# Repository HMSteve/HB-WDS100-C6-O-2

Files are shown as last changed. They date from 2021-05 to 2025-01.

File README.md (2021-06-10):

# HB-WDS100-C6-O-2

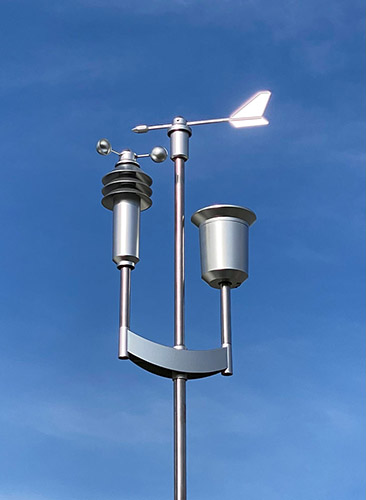
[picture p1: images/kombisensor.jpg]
HB-WDS100-C6-O-2


Ein "Reparaturset" fuer den Wetter-Kombisensor HM-WDS100-C6-O-2 auf Basis der AskSinPP-Bibliothek. Da Ausfaelle des originalen Wetter-Kombisensors wegen Korrosion der Hauptplatine offenbar nach einigen Jahren haeufiger vorkommen, die eigentliche Mechanik des Geraetes jedoch langlebig erscheint, wurde eine Ersatz-Elektronik sowie AskSinPP-basierte Firmware entwickelt, die es erlaubt, den Sensor ohne Modifikationen oder Addon-Installationen auf der CCU wieder zum Leben zu erwecken. Dazu sind sowohl die Hauptplatine als auch die Windrichtungsmesserplatine gegen die neu konzipierten Platinen auszutauschen und der Sensor neu anzulernen.

## Hardware

### Demontage des Kombisensors

Die Demontage des die Hauptplatine (und Batteriefach sowie Anemometer) tragenden Geraeteteils muss vorsichtig in folgenden Schritten erfolgen, um Schaeden an den Plastikteilen zu vermeiden:
1. Gehaeusehuelse ueber dem Batteriefach oeffnen und Batterien entfernen, Westernstecker loesen.
2. Beide Schrauben, die den Rotor mit den drei Schalen auf der Welle halten, leicht loesen und Rotor abziehen.
3. Zwei unter der Rotorkappe sichtbarwerdende vierkantige Arretierungsstifte aus Platik vorsichtig nach oben herausziehen (etwas mit dem Schraubenzieher hebeln, dann mit der Zange greifen und senkrecht herausziehen)
4. Die drei Ringe zum Sonnen- und Wetterschutz (Stevenson-Screen) mit dem oberen beginnend leicht im Urzeigersinn drehen, dass sich der jeweilige Bajonettverschluss loest, und Ring senkrecht nach oben abziehen.
5. Zwei kleine Schrauben ganz oben am Lager der Welle sowie danach fuenf lange Gehaeuseschrauben entfernen.
6. Zwei Schrauben, die den Aufbau auf dem Edelstahlrohr fixieren, loesen und Aufbau senkrecht nach oben aus dem Rohr Heraus ziehen
7. Die beiden Gehaeusehalbschalen lassen sich nun trennen und die defekte Platine ausbauen. Die Kabel koennen in der anderen Gehaeusehalbschale verbleiben.

Die Demontage der Windrichtungsmesserplatine ist unproblematisch.

### Ersatzplatinen

Als Ersatz sind zwei neue Platinen herzustellen: [Schalt- und Bestueckungsplaene sowie Gerberfiles](https://github.com/HMSteve/HB-WDS100-C6-O-2/tree/main/PCB).

Die Platinen sind bzgl. Bauteilbauformen, Padgroessen und Abstaenden grundsaetzlich fuer Handloetung vorgesehen, Details siehe unten.

Fuer die etwas spezielleren Bauteile finden sich Bezugsquellen hier: [Bezugsquellen](https://github.com/HMSteve/HB-WDS100-C6-O-2/tree/main/PCB/SourcingSpecialParts.xlsx)

### Hauptplatine

Die Platine basiert auf einem ATMega1284p. Die Temperatur-/Luftfeuchtemessung erfolgt mit einem SHT31, die Helligkeitsmessung mit einem [VEML6030](https://github.com/HMSteve/HB-WDS100-C6-O-2/blob/main/datasheets/VEML6030.pdf). Die Windgeschwindigkeit wird wie im Original per Reedkontakt gezaehlt, zur Reduzierung des Stromverbrauchs wird zum Zaehlen ein [PCF8593](https://github.com/HMSteve/HB-WDS100-C6-O-2/blob/main/datasheets/PCF8593.pdf) eingesetzt.

Ein paar Fotos vom Aufbau:

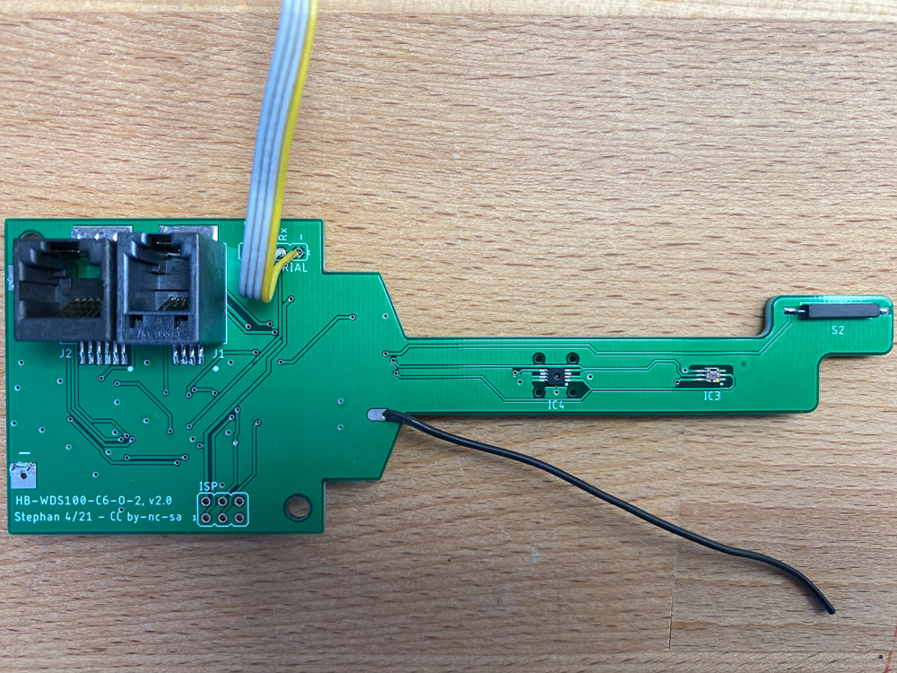
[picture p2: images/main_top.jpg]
PCB Top


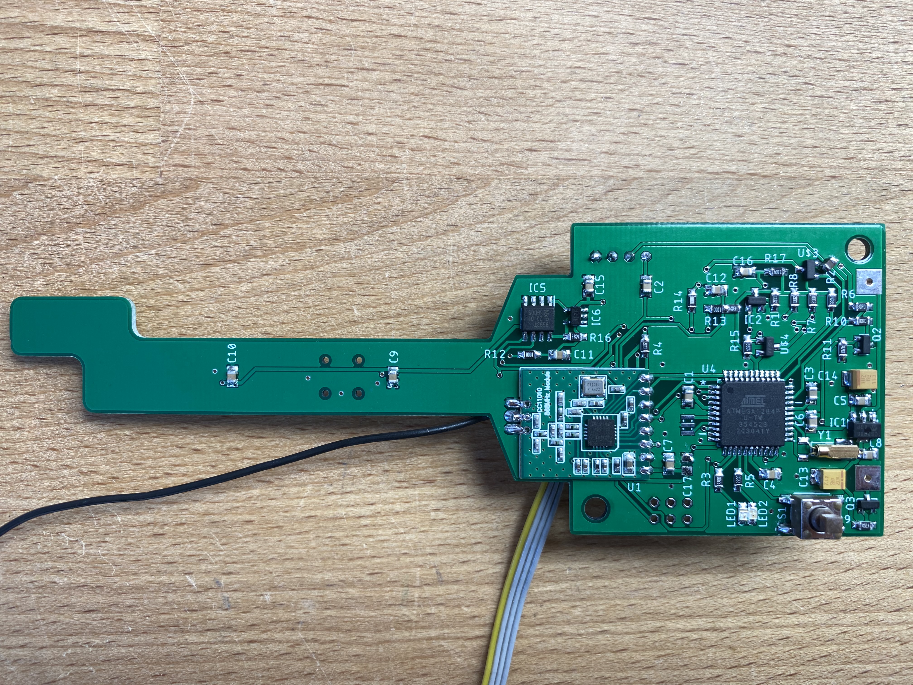
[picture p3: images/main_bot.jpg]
PCB Bottom


Bei Bestueckung der als Layout und Gerberfiles vorliegenden Platine v2.0 sind zwei Fehler zu korrigieren. Dazu ist jeweils etwas Loetstoplack zu entfernen, um die geaenderten Bauteilpostionen bestuecken zu koennen.

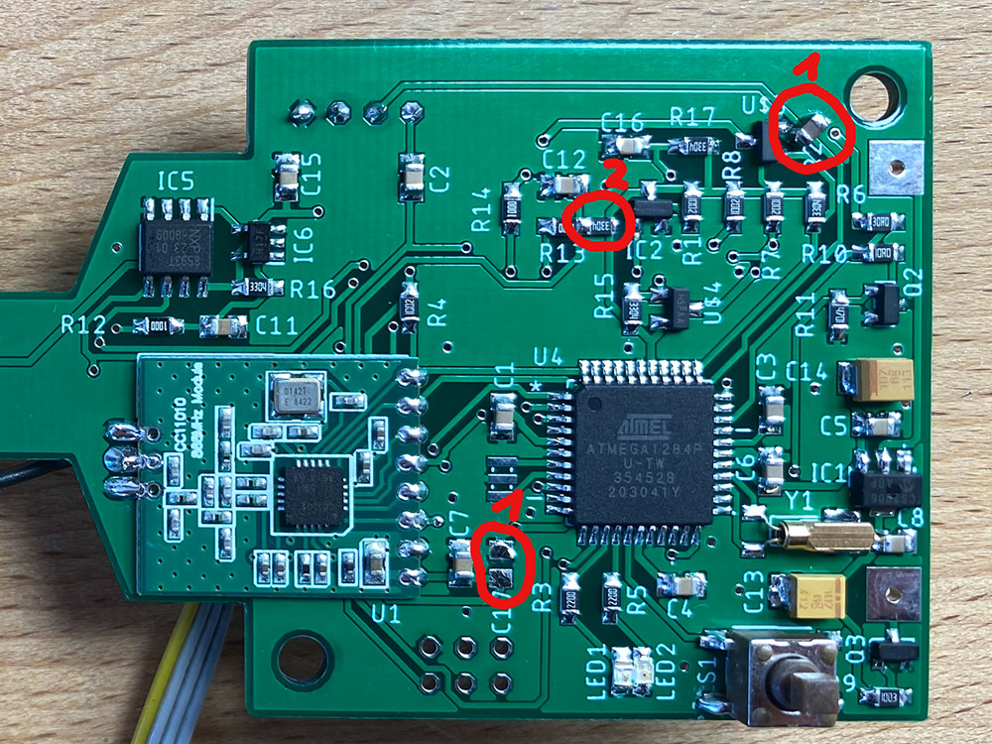
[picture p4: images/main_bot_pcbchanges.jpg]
PCB Bottom Changes


1. C17 ist nicht direkt am CC1101-Modul zu bestuecken, sondern direkt vor dem FET zur Abschaltung der Betriebsspannung bzw. an der dort vorhandenen Durchkontaktierung gegen die Masseflaeche. Ohne diese Aenderung koennen die Einschaltstromspitzen zu einem Brownout des ATMega fuehren und die Schaltung laeuft nicht oder geraet in eine Reset-Schleife.
2. Der markierte 3.3M-Pullup-Widerstand gegen 3.3V fehlt im Layout und ist wie gezeigt zu ergaenzen. Auf Grund der Konstruktion der Regenzaehlerwippe, deren Reedkontakt in einer stabilen Wippenstellung stets geschlossen ist, scheidet die Nutzung des niederohmigen internen pull-up des ATMega wegen des Energieverbrauchs aus.

Der korrigierte [Schaltplan v2.1](https://github.com/HMSteve/HB-WDS100-C6-O-2/blob/main/PCB/HB-WDS100-C6-O-2_Main_v2p1Schematic.pdf) (ohne Platinenlayout-Aenderung) zeigt die korrekte Schaltung.

Zunaechst sind alle Bauteile ausser dem SHT31 zu bestuecken und die Platine bspw. mit Isopropanol von Flussmittelresten zu reinigen. Ganz zum Schluss wird der SHT31 bestueckt und die Schutzkappe aufgesetzt. Der Sensor darf Loesungsmitteln nicht ausgesetzt werden.

Waehrend die Bestueckung und Loetung von Hand fuer fast alle Bauteile unproblematisch ist, gestaltet sich die Handloetung des SHT31 und VEML6030 aber etwas schwieriger. Mit Lupenbrille oder Mikroskop und geregeltem Loetkolben mit guter Spitze ist dies moeglich. Empfehlenswerter ist jedoch Reflowloeten, wobei die Sensoren nicht von oben mit Heissluft oder Infrarotstrahlung erhitzt werden sollten. Da die Platinenunterseite unter den Sensoren frei ist, bietet sich Erhitzung von unten mit Heissluft hat. Das Auftragen der Lotpaste wird mittels Schablone stark vereinfacht - Standardschablonen sind bspw. bei [Proto-Advantage](https://www.proto-advantage.com/) erhaeltlich.

Der besonders der Witterung ausgesetzte schmale (obere) Teil der Platine sollte wenn moeglich dennoch mittels Schutzlack geschuetzt werden, um die Witterungsbestaendigkeit zu erhoehen. Auch hierbei ist der SHT31 vor Loesungsmitteln zu schuetzen, bspw. durch Aufpinseln statt Spruehen von [FSC](https://electrolube.com/product/fsc-flexible-silicone-conformal-coating/) auf die Platine, nicht jedoch auf die Schutzkappe des Sensors, und Trocknung in einem gut beluefteten warmen Raum.

Beim Einbau der Platine in das Gehaeuse sollte die Aussparung, durch die der schmale Platinenteil sowie der Antennendraht gefuehrt werden, beidseitig wie im Foto zu sehen mit neutral vernetzendem Silikon abgedichtet werden.

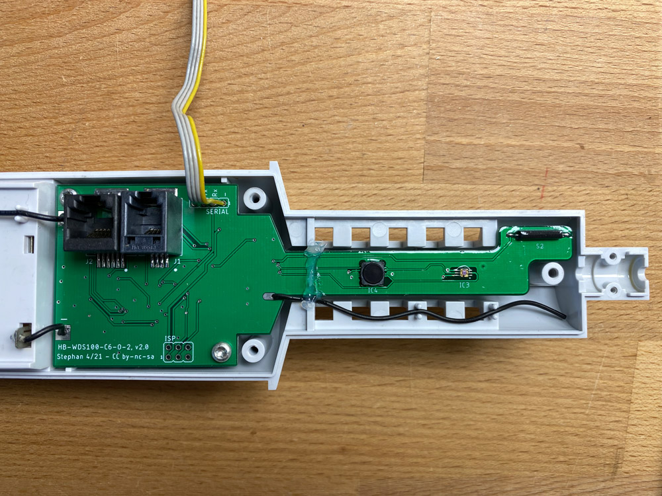
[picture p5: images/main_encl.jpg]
Einbau Main


### Windrichtungsmesserplatine

Auch wenn die Original-Windrichtungsmesserplatine kaum korrosionsanfaellig montiert und vermutlich nicht defekt ist, wurde zur einfacheren Einbindung in die gewaehlte AVR-Erchitektur auch diese neu erstellt. Genutzt wird ein [AS5600](https://github.com/HMSteve/HB-WDS100-C6-O-2/blob/main/datasheets/AS5600.pdf) Halleffekt-Drehwinkelsensor, der ueber einen FET auf der Hauptplatine zwischen den Messungen zur Verringerung des Stromverbrauchs abgeschaltet wird.

Der Aufbau erfolgt ohne Besonderheiten. Der Loetjumper SJ1 ist entsprechend dem Foto gegen Masse zu schliessen.

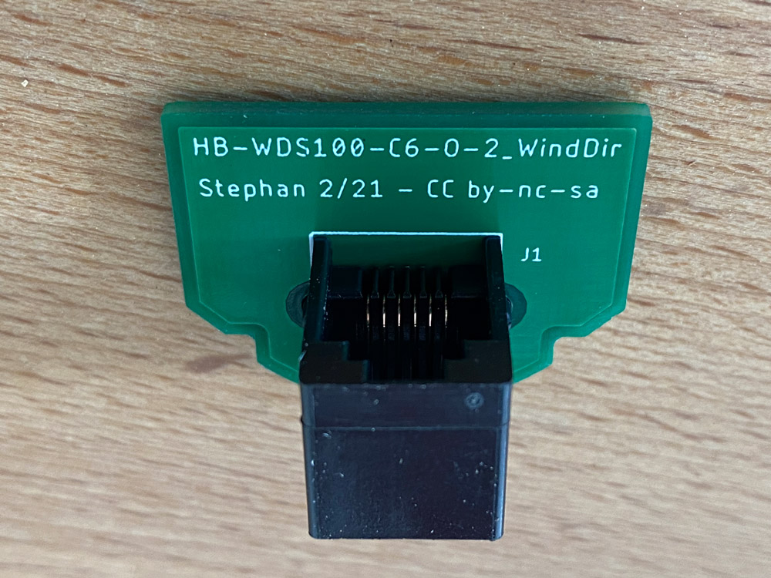
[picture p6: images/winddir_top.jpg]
PCB Top 2


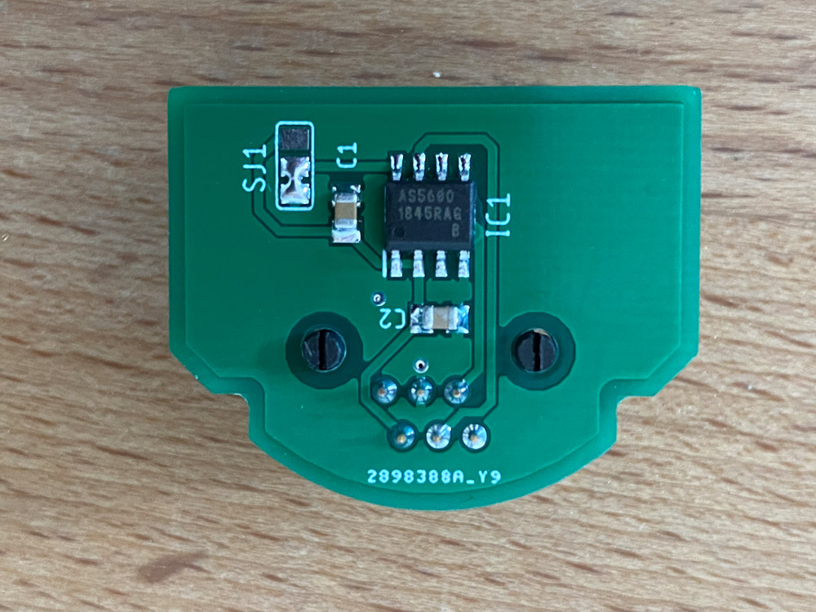
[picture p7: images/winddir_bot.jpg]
PCB Bottom 2


## Firmware

Zur Verwendung des ATMega1284p ist bei Nutzung der Arduino IDE zunaechst eine zusaetzliche sog. Boardverwalter-URL (https://mcudude.github.io/MightyCore/package_MCUdude_MightyCore_index.json) in den Voreinstellungen zu hinterlegen. Folgende Boardeinstellungen sind dann auszuwaehlen:

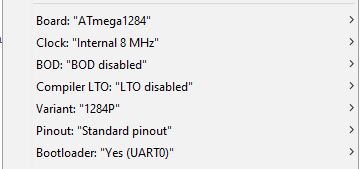
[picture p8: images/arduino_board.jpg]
Boardeinstellungen


Danach kann der Bootloader geflashed werden.

Sollte versehentlich externer Takt oder Quarzoszillator eingestellt oder die entsprechenden Fuses anderweitig falsch gesetzt worden sein, kann auf der Platine ein 8MHz-Resonator CSTNE von Murata bestueckt werden, um den Controller zu retten. Fuer den Normalbetrieb ist der Resonator nicht notwendig.

Um die [Firmware](https://github.com/HMSteve/HB-WDS100-C6-O-2/tree/main/Firmware)  zu kompilieren, muessen sich die .ino sowie die .h Dateien im gleichen Verzeichnis befinden, das ./sensors-Verzeichnis darunter. Zudem muss eine Reihe von Bibliotheken ueber den Library Manager eingebunden werden:
- AskSinPP
- EnableInterrupt
- LowPower
- Adafruit_SHT31 Arduino Library
- PCF8583 Library (Diese wird hier fuer den stromsparenderen PCF8593 genutzt.)

Anschliessend sollte die Firmware problemlos kompilierbar und das Device nach dem Flashen anlernbar sein.

## Bedienung

Die Bedienung erfolgt grundsaetzlich analog dem originalen HM-WDS100-C6-O-2. Der Sensor kann an eine CCU angelernt werden. Direktverknuepfungen zum Steuerun von Aktoren abhaengig von der Windgeschwindigkeit sind moeglich. Lediglich der Live Mode ist nicht implementiert.

### Geraetetaste

Die Geraetetaste weist folgende Funktionen auf:
- kurzer Druck: Anlernmodus starten / Konfiguration uebernehmen (LED langsam rot blinkend)
- langer Druck: Einnordungsmodus starten (kurzes Blinkmuster der roten LED)
- sehr langer Druck: Zuruecksetzen auf Werkseinstellung (einmaliges Aufleuchten der gruenen LED)

### Einnorden

Bei Erstinstallation nach Montage ist der Einnordungsmodus durch langen Druck der Geraetetaste zu starten, die Windfahne Richtung Norden auszurichten und so festzuhalten und sodann die Geraetetaste kurz zu druecken. Das Abspeichern des absoluten Winkels der Nordrichtung im EEPROM wird durch Aufleuchten der gruenen LED bestaetigt. Erfolgt dies nicht, ist der Vorgang zu wiederholen.

### Helligkeit und Windgeschwindigkeit

Um den geringen Dynamikumfang des Originalsensors etwas zu verbessern und insbesondere Helligkeiten in der Daemmerung sinnvoll auswerten zu koennen, wird die Beleuchtungsstaerke in Lux logarithmiert und auf den 8-Bit-Wertebereich skaliert ausgegeben. 100 kLux entsprechen etwa einem Wert von 220, 100 Lux noch immer etwa einem Wert von 80.

Die Windgeschwindigkeit wurde mit Hausmitteln (Hand-Schalenanemometer und Laubblasgeraet) kalibriert, bei 35 Messungen ergab sich eine Regression mit Bestimmtheitsmass 0.9. Im Gegensatz zum Originalsensor werden auch hoehere Windgeschwindigkeiten noch gemessen.

### Hinweise zum Energieverbrauch

Die mittlere Stromaufnahme des Sensors bei einem Sendeintervall von etwa 3 Minuten betraegt knapp 30uA, so dass eine Batterielaufzeit von einigen Jahren erreichbar sein sollte.  

## Disclaimer

Die Nutzung der hier veroeffentlichten Inhalte erfolgt vollstaendig auf eigenes Risiko und ohne jede Gewaehr.

## Lizenz

**Creative Commons BY-NC-SA**<br>
Give Credit, NonCommercial, ShareAlike

<br />This work is licensed under a <a rel="license" href="http://creativecommons.org/licenses/by-nc-sa/4.0/">Creative Commons Attribution-NonCommercial-ShareAlike 4.0 International License</a>.

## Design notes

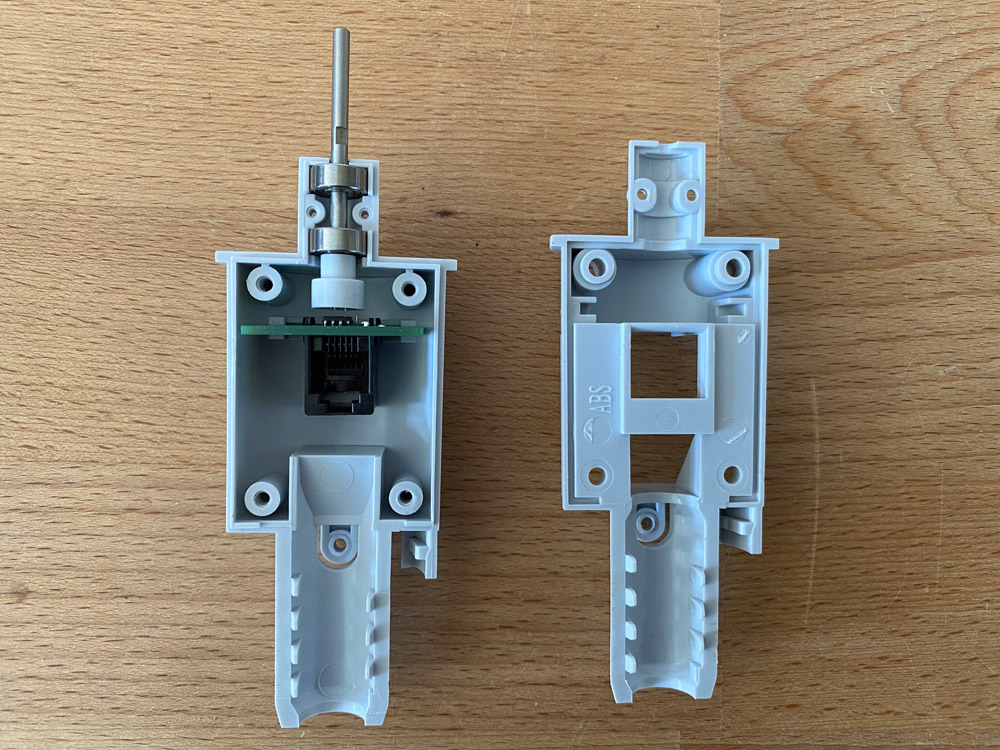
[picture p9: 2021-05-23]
images/winddir_encl.jpg

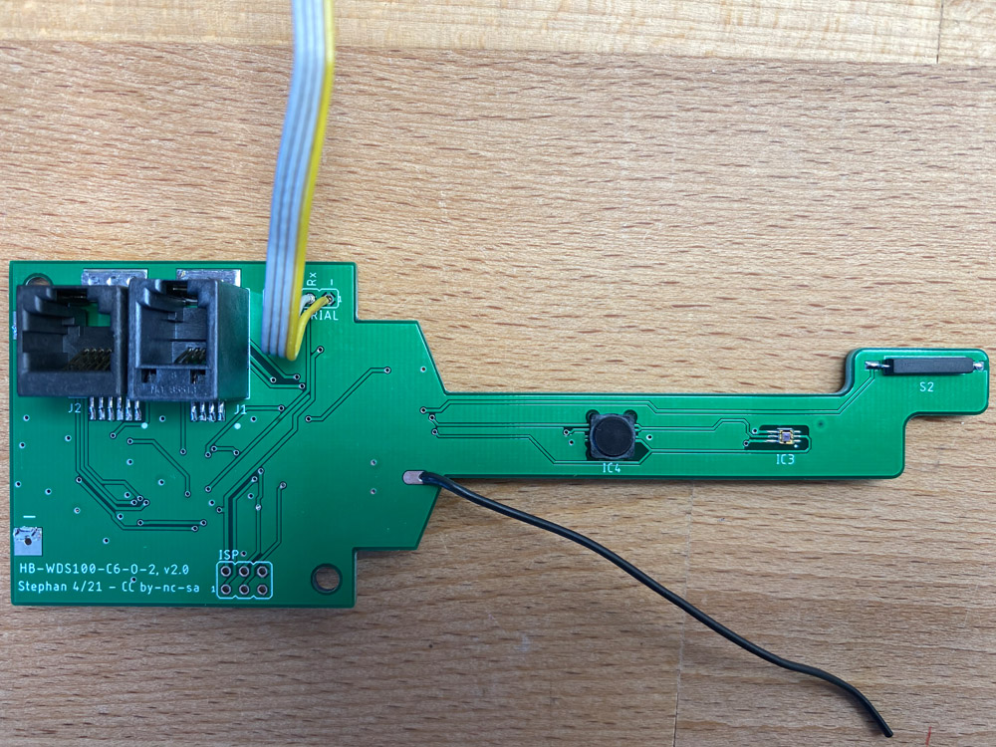
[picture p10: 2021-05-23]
images/main_top_cap.jpg

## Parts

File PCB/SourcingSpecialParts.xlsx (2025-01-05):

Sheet: Mouser
Part | Mouser No | Mfr. No | Manufacturer | Description
IC1 | 579-MCP1700T3302E/TT | MCP1700T-3302E/TT | Microchip | LDO Voltage Regulators 250mA Adj LDO 2%
IC1 WindDir | 985-AS5600-ASOT | AS5600-ASOT | ams | Board Mount Hall Effect/Magnetic Sensors AS5600 Magnetic Sensor 12-Bit
IC2 | 579-MCP111T-270E/TT | MCP111T-270E/TT | Microchip | Supervisory Circuits Open Drain
IC3 | 78-VEML6030-GS15 | VEML6030-GS15 | Vishay | Ambient Light Sensors Opr 2.5-3.6V 0.005x Filtron O-Trim 16Bit
IC4 | 403-SHT31-DIS-P2.5KS | SHT31-DIS-P2.5KS | Sensirion | Board Mount Humidity Sensors RH/ T Sensor
IC5 | 771-PCF8593TD-T | PCF8593T/1,118 | NXP | Real Time Clock CLOCK/CALENDAR RTC IC
IC6 | 595-SN74AUP1G17DBVR | SN74AUP1G17DBVR | Texas Instruments | Buffers & Line Drivers Lo Pwr Sngl Schmtt Trggr Invrtr
J1 | 538-85513-5016 | 85513-5016 | Molex | Modular Connectors / Ethernet Connectors 4P SMT JACK
J1 WindDir | 710-615006138421 | 615006138421 | Wurth Elektronik | Modular Connectors / Ethernet Connectors WR-MJ Female Plastic 6P6C Horztl Tab Up
J2 | 710-634106149621 | 634106149621 | Wurth Elektronik | Modular Connectors / Ethernet Connectors WR-MJ Mod Jk 6P6C Solder Tab w/Mylar
Q1 | 81-CSTNE8M00GH5C000R | CSTNE8M00GH5C000R0 | Murata | Resonators 8.0000MHz 33pF SMD CHP Rsntr 0.07% AUTO
Q2, Q3 | 942-IRLML6344TRPBF | IRLML6344TRPBF | Infineon | MOSFET MOSFT 5.0A 29mOhm 30V 2.5V drv capable
S1 | 612-TL3301TF100QG | TL3301TF100QG | E-Switch | Tactile Switches SMT Tact Switch SPST-NO 0.05A 12V
S2 | 876-MK16-B-2 | MK16-B-2 | Standex Electronics | Proximity Sensors 1 Form A Surface Mount
U$3, U$4 | 78-SI2365EDS-T1-GE3 | SI2365EDS-T1-GE3 | Vishay | MOSFET -20V Vds 8V Vgs SOT-23
U4 | 556-ATMEGA1284P-AUR | ATMEGA1284P-AUR | Microchip | 8-bit Microcontrollers - MCU AVR,128KB FLASH,1.8V 4KB EE 16KB SRAM
Y1 | 428-200123-ML02 | MS1V-T1K-32.768kHz-6pF-20PPM-TA-QC-Au | Micro Crystal | Quarze 32.768 kHz 6.0 pF +/-20 PPM -40/+85C

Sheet: Digikey
Part | Digikey-Teilenummer | Hersteller-Teilenummer | Beschreibung
IC2 | MCP111T-270E/TTCT-ND | MCP111T-270E/TT | IC SUPERVISOR 1 CHANNEL SOT23-3
U4 | ATMEGA1284P-AU-ND | ATMEGA1284P-AU | IC MCU 8BIT 128KB FLASH 44TQFP
IC3 | VEML6030CT-ND | VEML6030 | SENSOR OPT 550NM AMBIENT 6SMD
IC4 | 1649-1083-1-ND | SHT31-DIS-P2.5KS | SENSOR HUMID/TEMP 5V I2C 2% SMD
IC6 | 296-19077-1-ND | SN74AUP1G17DBVR | IC BUF NON-INVERT 3.6V SOT23-5
IC5 | 568-1090-1-ND | PCF8593T/1,118 | IC RTC CLK/CALENDAR I2C 8-SOIC
J1 | WM3555CT-ND | 0855135016 | CONN MOD JACK 4P4C VERT UNSHLD
J2 | 732-5940-1-ND | 634106149621 | CONN MOD JACK 6P6C VERT SHIELDED
C13, C14 | 399-10426-1-ND | T494B107K006AT | CAP TANT 100UF 10% 6.3V 1411

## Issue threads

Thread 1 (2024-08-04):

CLOCK_RTC funktioniert nicht sondern nur CLOCK_SYSCLOCK

mpietruschka, 2024-08-04:
Erstmal vielen Dank für das tolle Projekt. Die Bestellung der Platinen und Teile war wunderbar möglich und der Zusammenbau hat auch super funktioniert.

Ich betreibe den Sensor momentan am ISP mit dem Serial Konverter und ohne AS5600.

Beim Start des Sensors ist mir aufgefallen, dass er meist an folgender Stelle hängen bleibt.

```
AskSin++ v5.0.3 (Aug  4 2024 16:03:32)
SHT31 OK
VEML6030 OK
VEML6030 Gain               : 1.0000000000
VEML6030 Integration Time   : 400
VEML6030 Power Save Enabled : 1
VEML6030 Power Save Mode    : 4
PCF8593 init done, event counter mode set.
Address Space: 32 - 76
Radio init1
CC Version: 04
 - ready
```

Der folgende Teil kommt nur unvorhersehbar und danach passiert auch nichts mehr.

```
tmBatteryLoad Voltage: 4559
Battery set low:  32
Battery set crit: 30
* Device Conf Changed  : Wds100List0
* LED Mode             : 0
* Sendeversuche        : 6
* Live Mode            : 0
* Auszul. Meldungen    : 1
* Local Reset Disable  : 0
* Channel Conf Changed : Wds100List1
* Sonnescheinschwelle  : 10
* Sturm obere Schwelle : 0
* Sturm untere Schwelle: 0
* Art Windgeschw.      : 0
* Winkel Nord          : 0
```

Erst wenn ich von CLOCK_RTC auf CLOCK_SYSCLOCK umstelle, scheint der Sensor ordentlich zu laufen. Hat das irgendwelche Auswirkungen auf die Laufzeit?
Hast du vielleicht einen guten Tipp für mich wo der Fehler liegen könnte?
Der RTC müsste die Uhr im ATMega sein oder habe ich das auf asksin++ falsch verstanden?

HMSteve, 2025-01-21:
Sorry, habe das issue bis vor Kurzem uebersehen. Falls noch aktuell: Helfen die juengsten Hinweise im Forum [Forum](https://homematic-forum.de/forum/viewtopic.php?f=27&t=67875) weiter?

mpietruschka, 2025-01-26:
Hat geholfen. Es lag am fehlenden Quarz. Danke nochmal!

Closed 2025-01-26.

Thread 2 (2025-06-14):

Fertige Bauteile?

Flobo2012, 2025-06-14:
Guten Tag,

Ich bin bei einer Recherche zur defekten HMIP Wetterstation (wie auf dem von ihnen eingesetzten Bild) auf ihren Beitrag gestoßen.

Da unsere Station nur noch sporadisch Daten sendet und viel Strom verbraucht bin ich nun auf der Suche nach einer neuen und vorallem besseren Lösung.

Kann man die fertigen Platinen (geflasht, versiegelt) auch kaufen?

LG
Flo

HMSteve, 2025-06-14:
Hallo Flo,

Leider nicht, auch unbestueckte Platinen habe ich nicht mehr.

Viele Gruesse

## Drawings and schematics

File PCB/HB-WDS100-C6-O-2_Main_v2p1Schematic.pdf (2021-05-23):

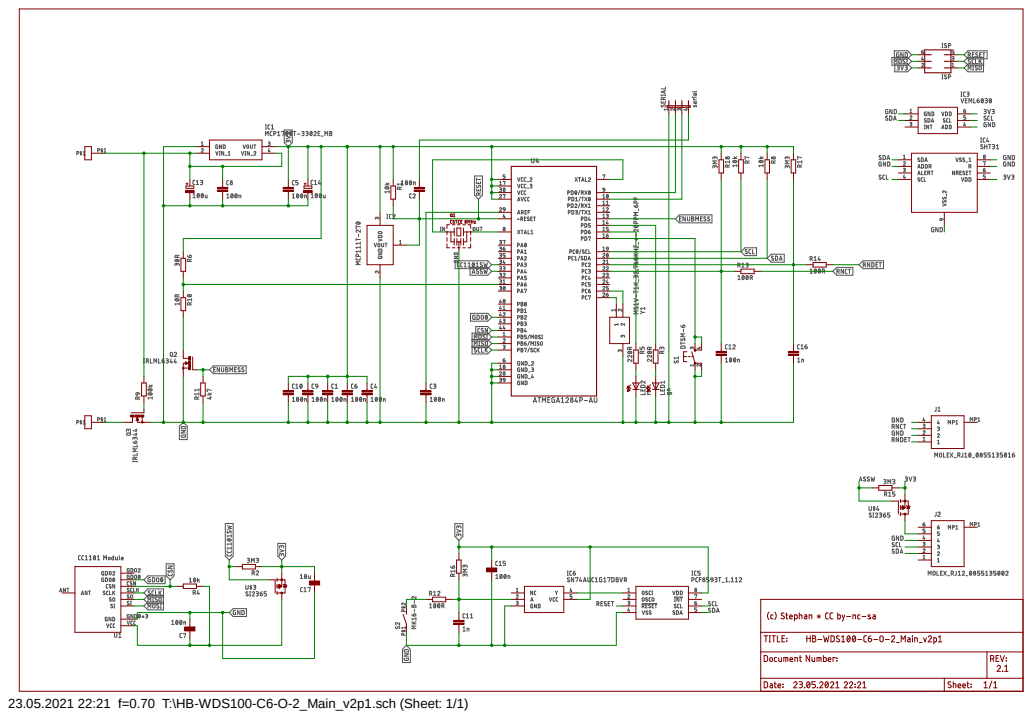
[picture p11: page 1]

23.05.2021 22:21 f=0.70 T:\HB-WDS100-C6-O-2_Main_v2p1.sch (Sheet: 1/1)

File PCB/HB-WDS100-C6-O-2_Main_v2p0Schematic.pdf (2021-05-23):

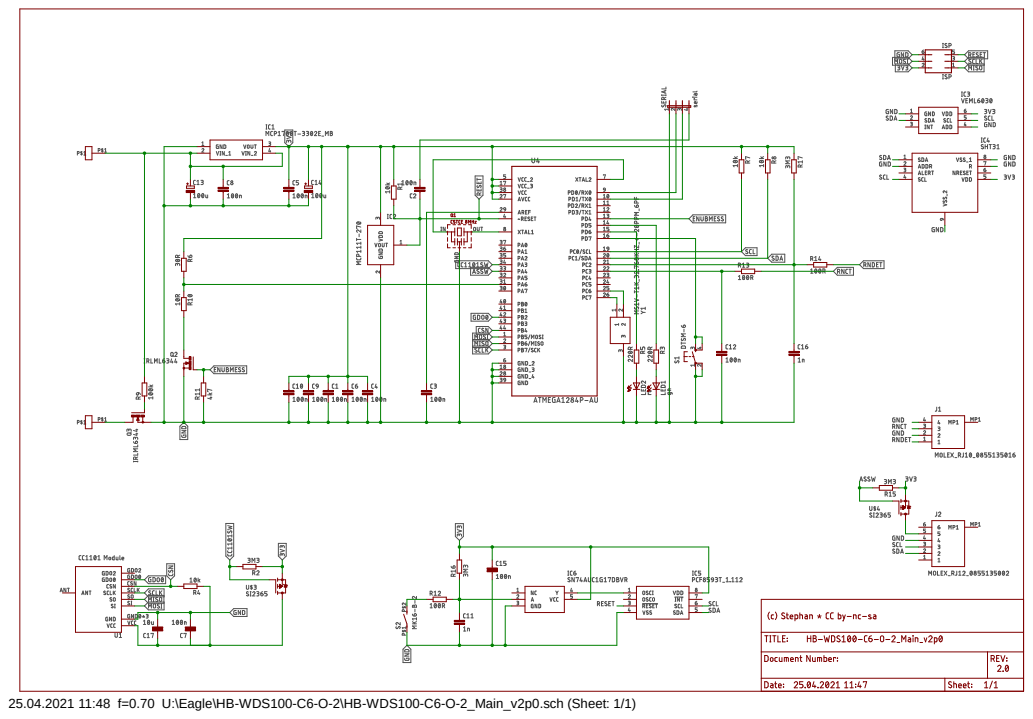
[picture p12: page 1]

25.04.2021 11:48 f=0.70 U:\Eagle\HB-WDS100-C6-O-2\HB-WDS100-C6-O-2_Main_v2p0.sch (Sheet: 1/1)

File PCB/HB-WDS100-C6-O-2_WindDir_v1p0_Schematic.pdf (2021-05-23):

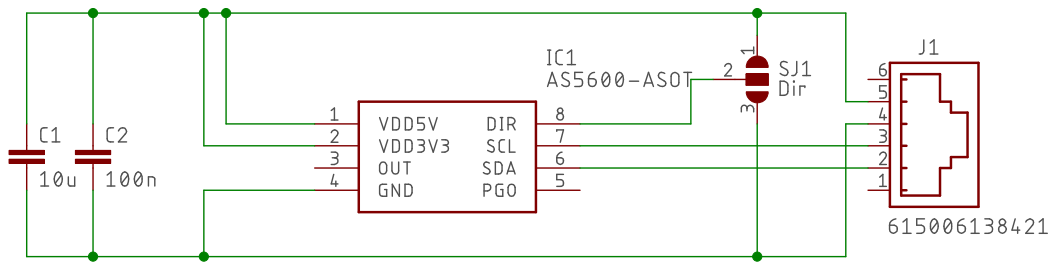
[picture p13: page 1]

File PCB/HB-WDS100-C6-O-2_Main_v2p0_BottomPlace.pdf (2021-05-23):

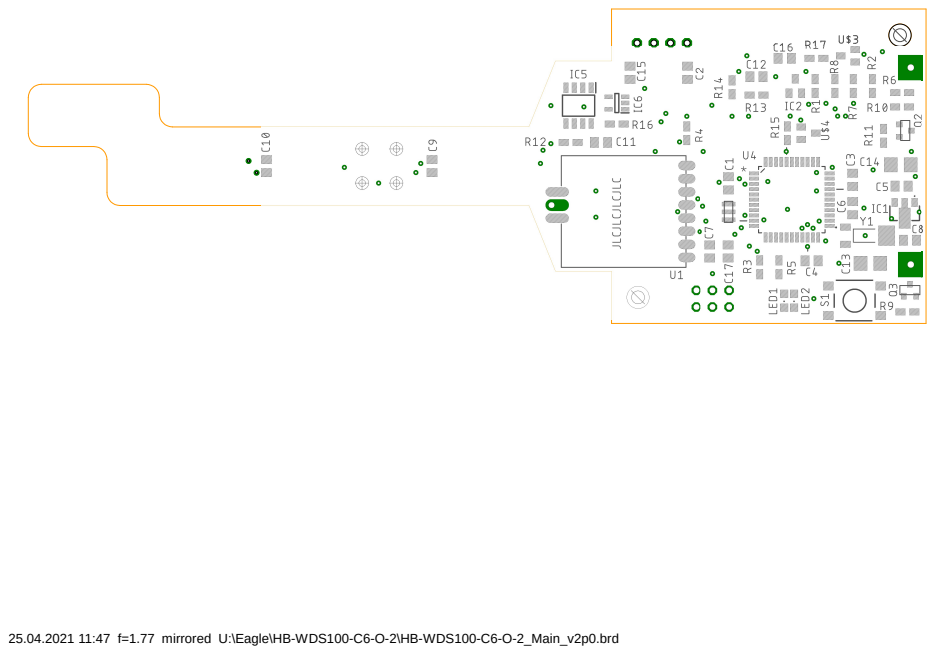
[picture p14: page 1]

25.04.2021 11:47 f=1.77 mirrored U:\Eagle\HB-WDS100-C6-O-2\HB-WDS100-C6-O-2_Main_v2p0.brd

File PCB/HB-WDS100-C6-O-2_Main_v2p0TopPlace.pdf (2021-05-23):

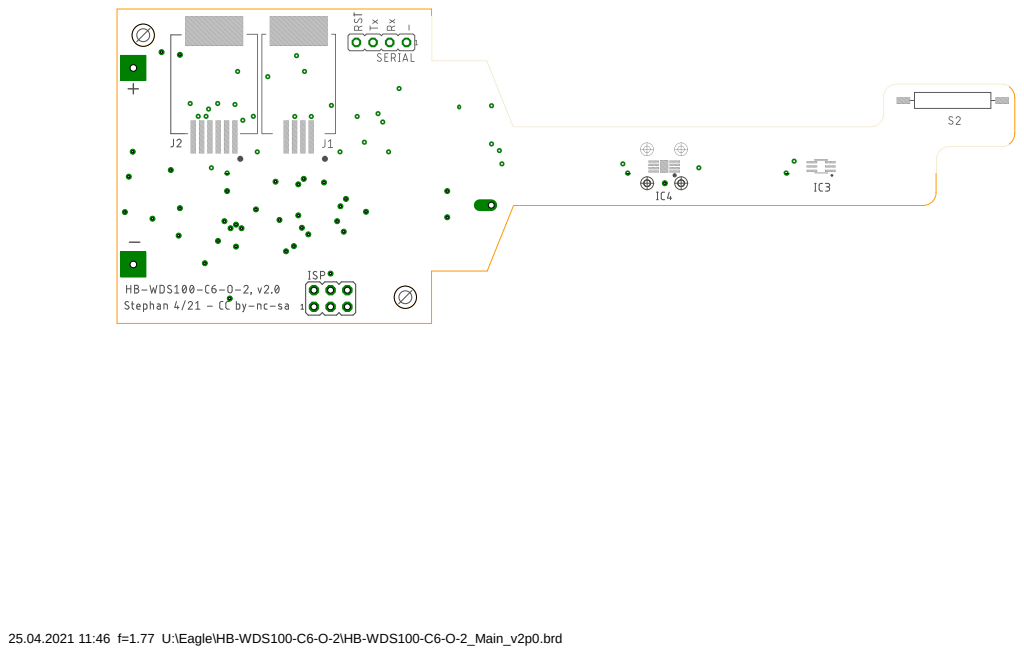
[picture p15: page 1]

25.04.2021 11:46 f=1.77 U:\Eagle\HB-WDS100-C6-O-2\HB-WDS100-C6-O-2_Main_v2p0.brd

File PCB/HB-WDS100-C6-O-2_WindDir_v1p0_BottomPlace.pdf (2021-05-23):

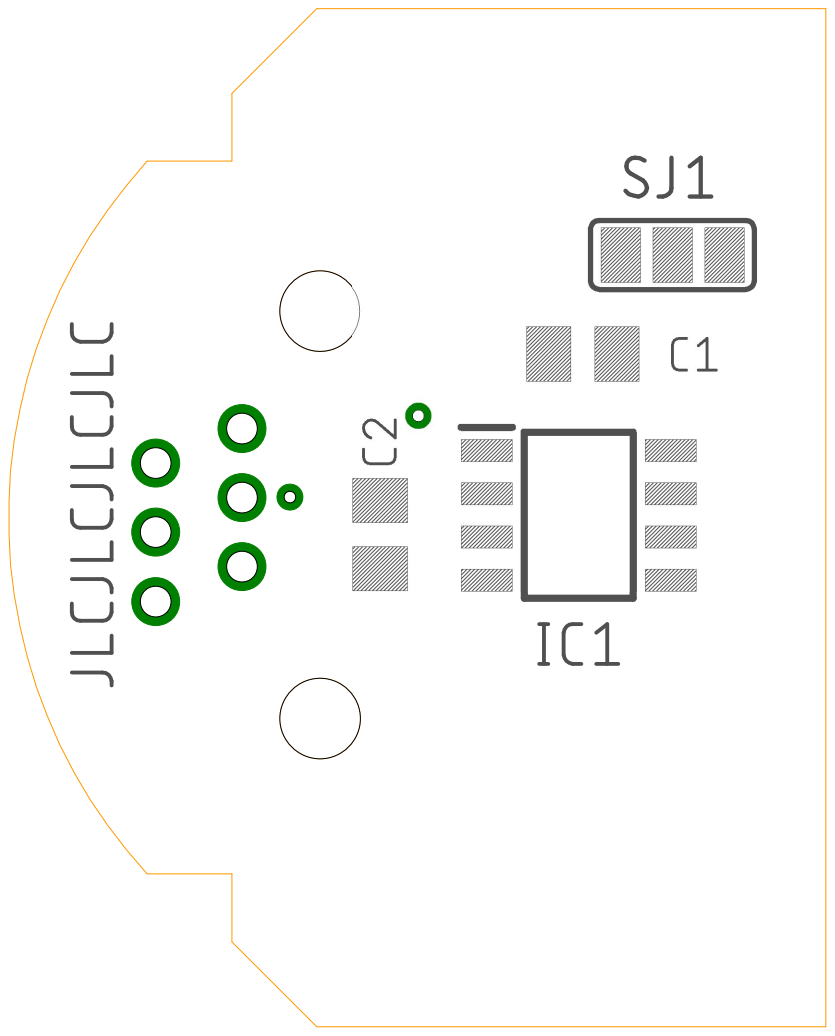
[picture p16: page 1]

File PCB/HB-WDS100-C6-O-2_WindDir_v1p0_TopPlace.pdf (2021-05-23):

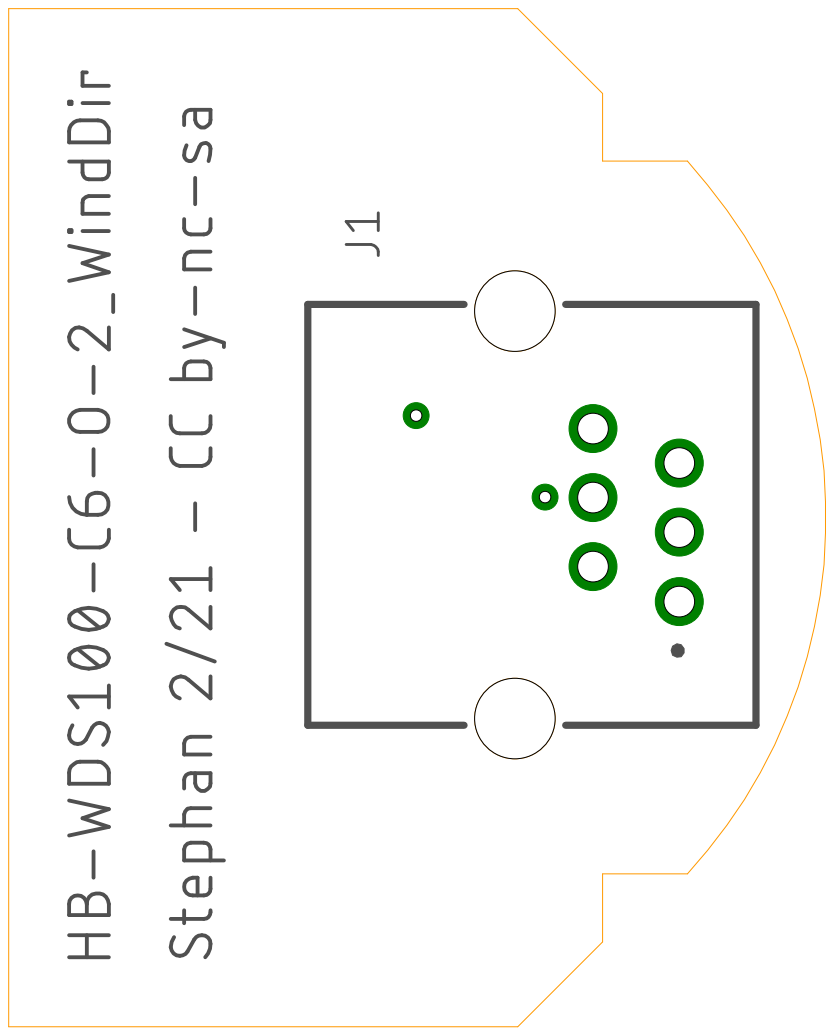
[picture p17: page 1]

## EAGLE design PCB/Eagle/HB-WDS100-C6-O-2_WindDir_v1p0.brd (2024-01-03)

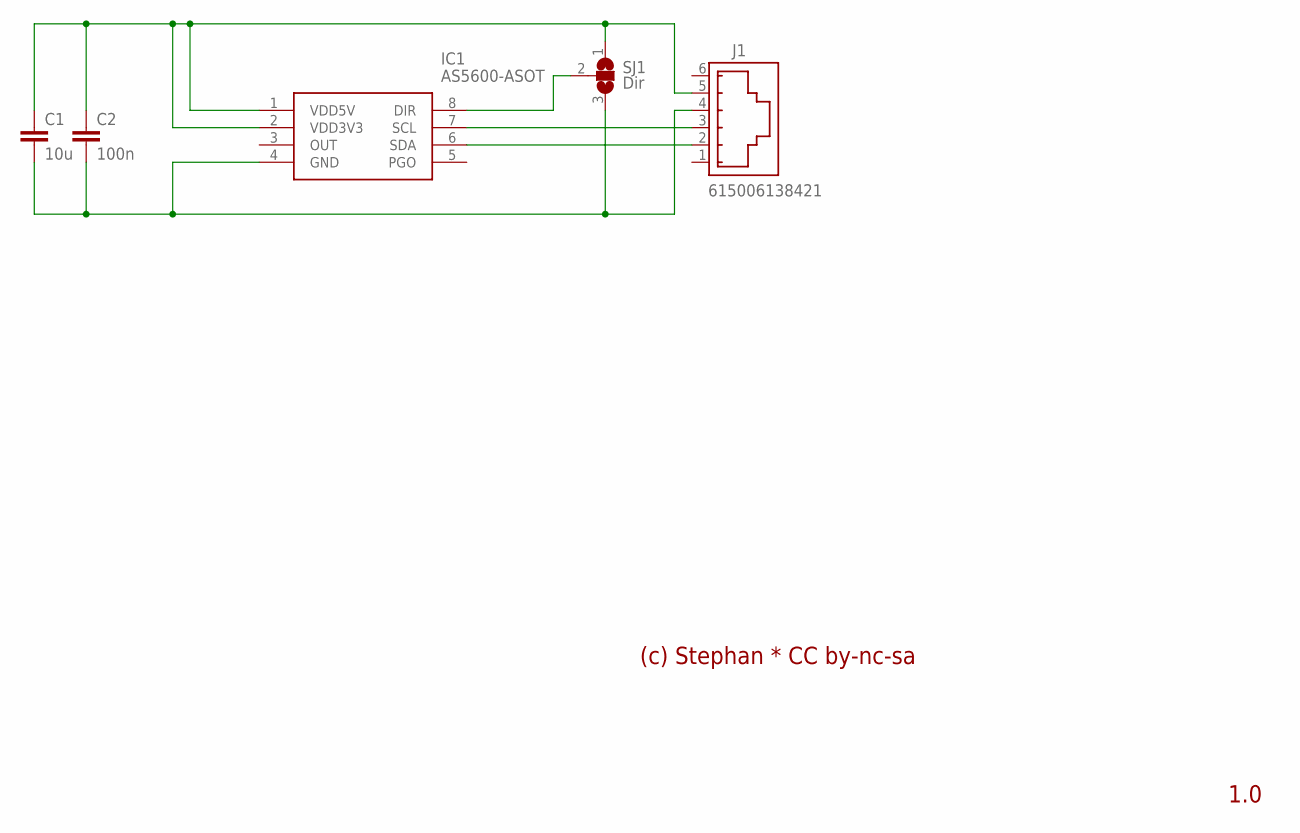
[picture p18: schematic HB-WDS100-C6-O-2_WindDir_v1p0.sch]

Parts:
C1: 10u; C0805K
C2: 100n; C0805K
IC1: AS5600-ASOT; SOIC127P600X175-8N
J1: 615006138421
SJ1: Dir; SJ_2

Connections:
3V3: C1.1, C2.1, IC1.1 (VDD5V), IC1.2 (VDD3V3), J1.5, SJ1.1
DIR: IC1.8 (DIR), SJ1.2
GND: C1.2, C2.2, IC1.4 (GND), J1.4, SJ1.3
SCL: IC1.7 (SCL), J1.3
SDA: IC1.6 (SDA), J1.2

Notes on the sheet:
(c) Stephan * CC by-nc-sa
1.0

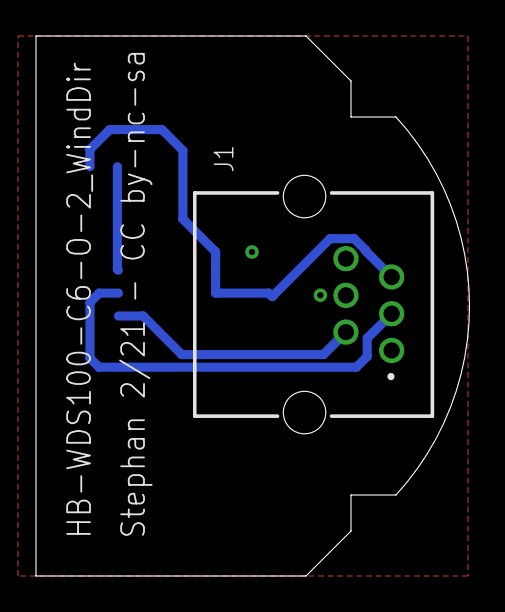
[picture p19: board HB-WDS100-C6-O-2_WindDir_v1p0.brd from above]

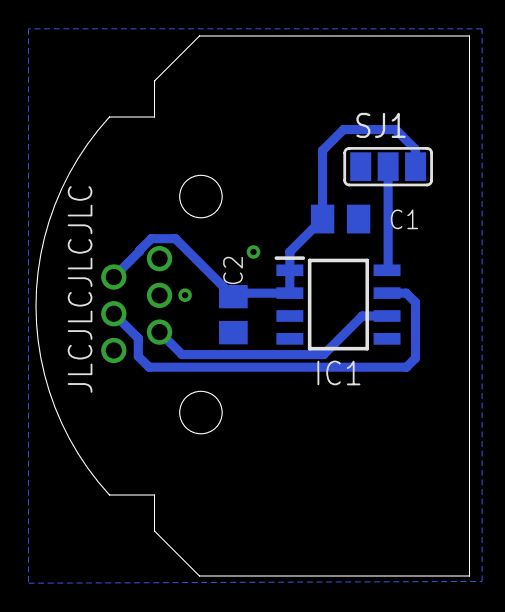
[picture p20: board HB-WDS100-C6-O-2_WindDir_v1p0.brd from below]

Board: 2 copper layers, 24.1 x 30.0 mm, 5 parts (4 on the bottom side), 5 nets.

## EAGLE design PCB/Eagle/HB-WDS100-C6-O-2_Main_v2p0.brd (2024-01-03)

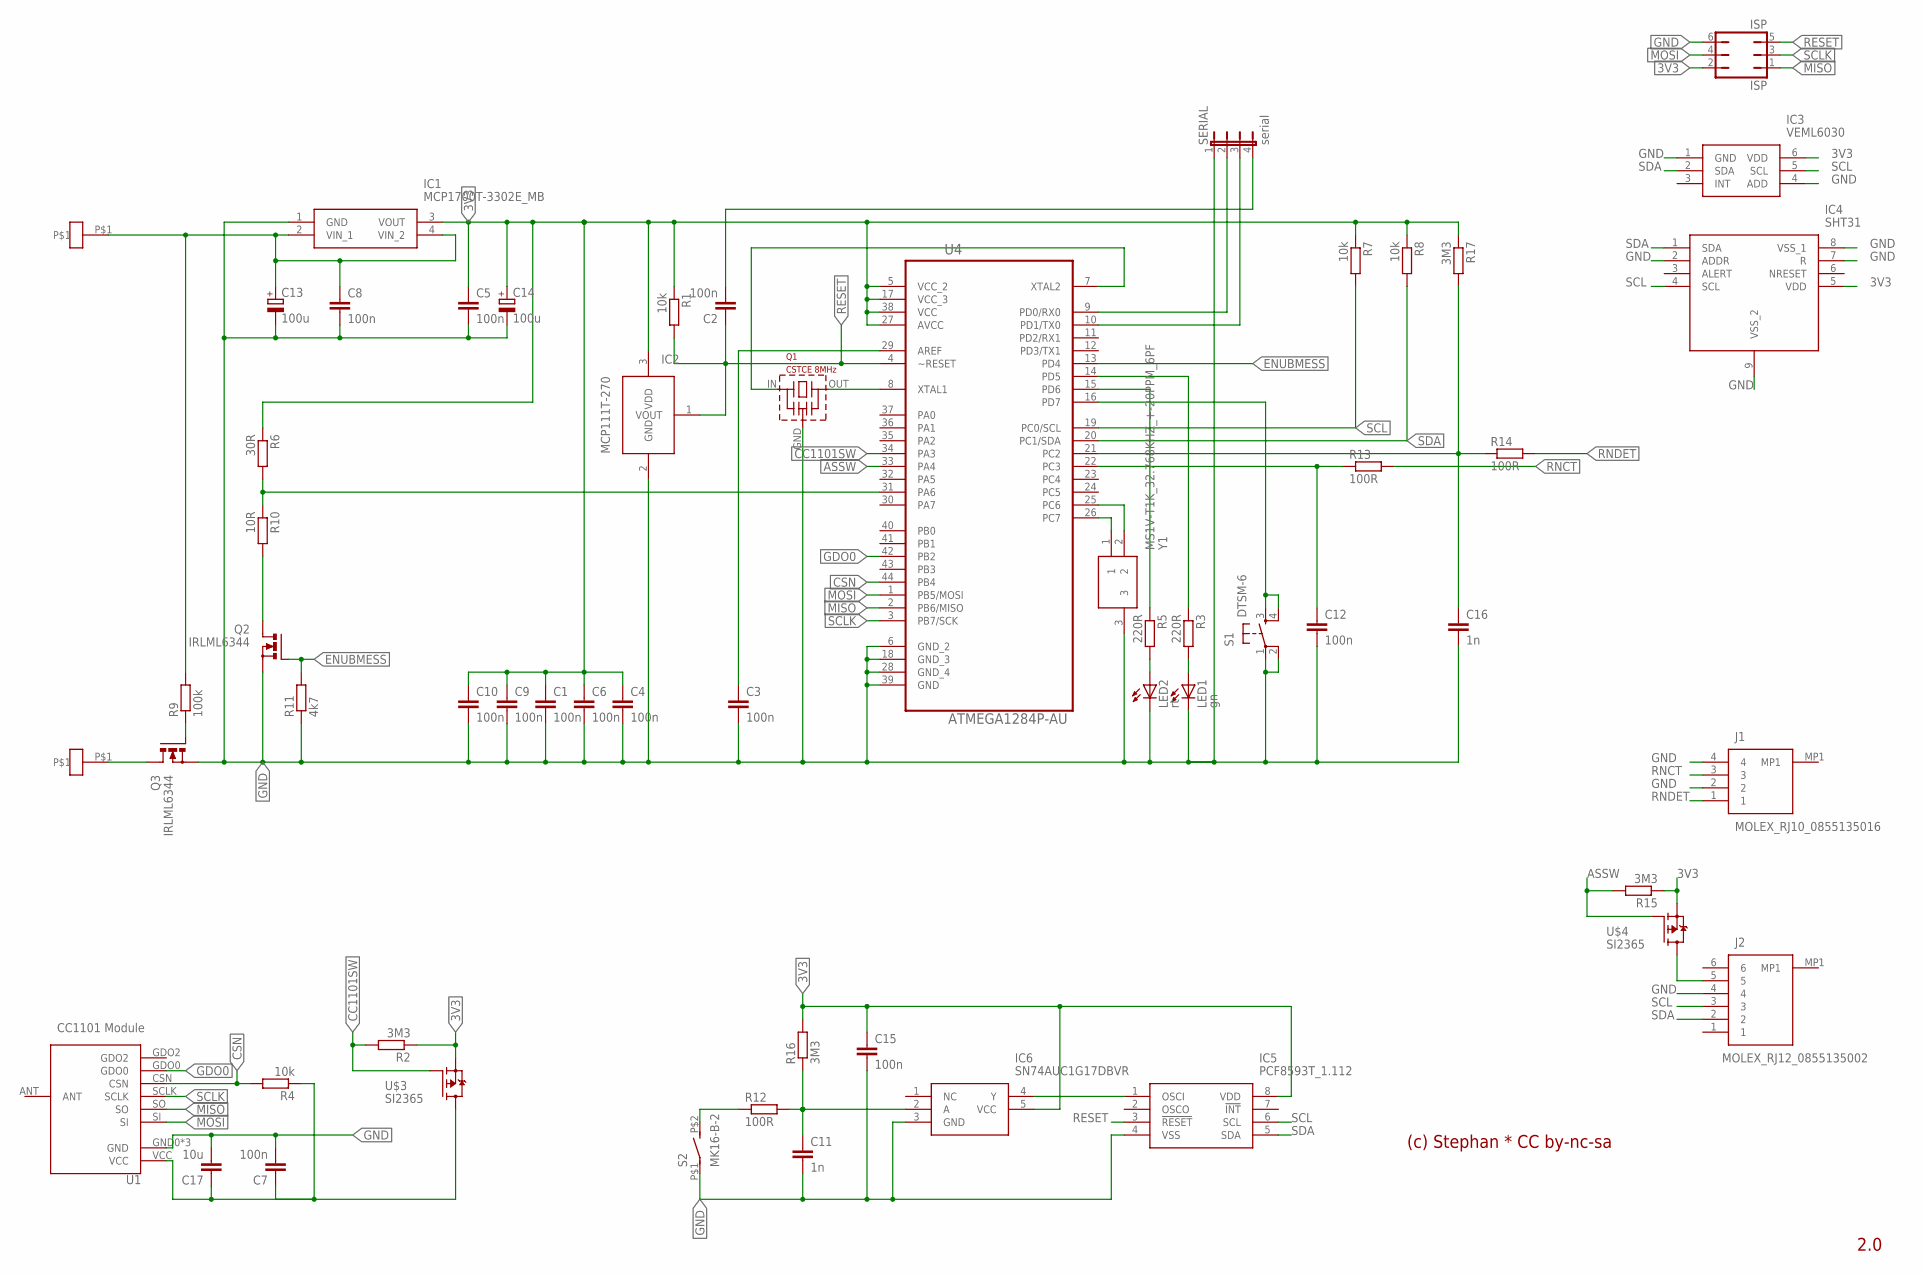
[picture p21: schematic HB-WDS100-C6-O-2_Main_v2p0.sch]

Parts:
C1, C2, C3, C4, C5, C6, C7, C8, C9, C10, C12, C15: 100n; C0805K
C11, C16: 1n; C0805K
C13, C14: 100u; CT3528
C17: 10u; C0805K
IC1: MCP1700T-3302E_MB; MCP1700T-3302E/MB
IC2: MCP111-270; SOT23
IC3: VEML6030; VEML6030-HANDSOLD
IC4: SHT31; SON50P250X250X90-9N-HANDSOLD
IC5: PCF8593T_1.112; SOIC127P600X175-8N
IC6: SN74AUC1G17DBVR; SOT95P280X145-5N
ISP: ISP; JP3Q
J1: MOLEX_RJ10_0855135016
J2: MOLEX_RJ12_0855135002
LED1: gn; CHIPLED_0805
LED2: rt; CHIPLED_0805
Q1: CSTCE 8MHz; CSTCE
Q2, Q3: IRLML6344; SOT-23
R1, R4, R7, R8: 10k; R0805W
R2, R15, R16, R17: 3M3; R0805W
R3, R5: 220R; R0805W
R6: 30R; R0805W
R9: 100k; R0805W
R10: 10R; R0805W
R11: 4k7; R0805W
R12, R13, R14: 100R; R0805W
S1: DTSM-6
S2: MK16-B-2
SERIAL: serial; JP4
U1: CC1101CC1101-SMD-2MM; CC1101-SMD2MM
U4: ATMEGA1284P-AU; QFP80P1200X1200X120-44N
U$1, U$2: LOETOESE
U$3, U$4: SI2365; SOT23
Y1: MS1V-T1K_32.768KHZ_+-20PPM_6PF; MS1VT1K32768KHZ20PPM6PF

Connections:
3V3: C1.1, C4.1, C5.1, C6.1, C9.1, C10.1, C14.+, C15.1, IC1.3 (VOUT), IC2.3 (VDD), IC3.6 (VDD), IC4.5 (VDD), IC5.8 (VDD), IC6.5 (VCC), ISP.2, R1.1, R2.1, R6.1, R7.1, R8.1, R15.1, R16.2, R17.1, U4.5 (VCC_2), U4.17 (VCC_3), U4.27 (AVCC), U4.38 (VCC), U$3.2 (S), U$4.2 (S)
3V3AS5600: J2.5, U$4.3 (D)
3V3CC1101: C7.1, C17.1, R4.1, U1.VCC, U$3.3 (D)
AREF: C3.1, U4.29 (AREF)
ASSW: R15.2, U4.33 (PA4), U$4.1 (G)
BATTMINUS: Q3.P3 (D), U$2.P$1
CC1101SW: R2.2, U4.34 (PA3), U$3.1 (G)
CSN: R4.2, U1.CSN, U4.44 (PB4)
ENUBMESS: Q2.P1 (G), R11.2, U4.13 (PD4)
GDO0: U1.GDO0, U4.42 (PB2)
GND: C1.2, C3.2, C4.2, C5.2, C6.2, C7.2, C8.2, C9.2, C10.2, C11.2, C12.2, C13.-, C14.-, C15.2, C16.2, C17.2, IC1.1 (GND), IC2.2 (GND), IC3.1 (GND), IC3.4 (ADD), IC4.2 (ADDR), IC4.7 (R), IC4.8 (VSS_1), IC4.9 (VSS_2), IC5.4 (VSS), IC6.3 (GND), ISP.6, J1.2, J1.4, J2.4, LED1.C, LED2.C, Q1.GND, Q2.P2 (S), Q3.P2 (S), R11.1, S1.1, S1.2, S2.P$1, SERIAL.1, U1.GND0 (GND), U1.GND1 (GND), U1.GND2 (GND), U4.6 (GND_2), U4.18 (GND_3), U4.28 (GND_4), U4.39 (GND), Y1.3
LED1: LED1.A, R3.2
LED1R: R3.1, U4.14 (PD5)
LED2: LED2.A, R5.2
LED2R: R5.1, U4.15 (PD6)
MISO: ISP.1, U1.SO, U4.2 (PB6/MISO)
MOSI: ISP.4, U1.SI, U4.1 (PB5/MOSI)
OSC1: U4.25 (PC6), Y1.2
OSC2: U4.26 (PC7), Y1.1
PCFIN: IC5.1 (OSCI), IC6.4 (Y)
Q3GATE: Q3.P1 (G), R9.1
REEDSW: R12.1, S2.P$2 (S)
RESET: C2.1, IC2.1 (VOUT), IC5.3 (!RESET), ISP.5, R1.2, U4.4 (~RESET)
RNCT: J1.3, R13.2
RNCTPIN: C12.1, R13.1, U4.22 (PC3)
RNDET: J1.1, R14.2
RNDETPIN: C16.1, R14.1, R17.2, U4.21 (PC2)
RX: SERIAL.2, U4.9 (PD0/RX0)
SCL: IC3.5 (SCL), IC4.4 (SCL), IC5.6 (SCL), J2.3, R7.2, U4.19 (PC0/SCL)
SCLK: ISP.3, U1.SCLK, U4.3 (PB7/SCK)
SDA: IC3.2 (SDA), IC4.1 (SDA), IC5.5 (SDA), J2.2, R8.2, U4.20 (PC1/SDA)
SERIALRESET: C2.2, SERIAL.4
STIN: C11.1, IC6.2 (A), R12.2, R16.1
SW1: S1.3, S1.4, U4.16 (PD7)
TX: SERIAL.3, U4.10 (PD1/TX0)
UBATT: C8.1, C13.+, IC1.2 (VIN_1), IC1.4 (VIN_2), R9.2, U$1.P$1
UBMESS: R6.2, R10.1, U4.31 (PA6)
VOLTDEVFOOT: Q2.P3 (D), R10.2
XTAL1: Q1.OUT, U4.8 (XTAL1)
XTAL2: Q1.IN, U4.7 (XTAL2)

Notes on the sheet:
MCP111T-270
(c) Stephan * CC by-nc-sa
2.0
CC1101 Module

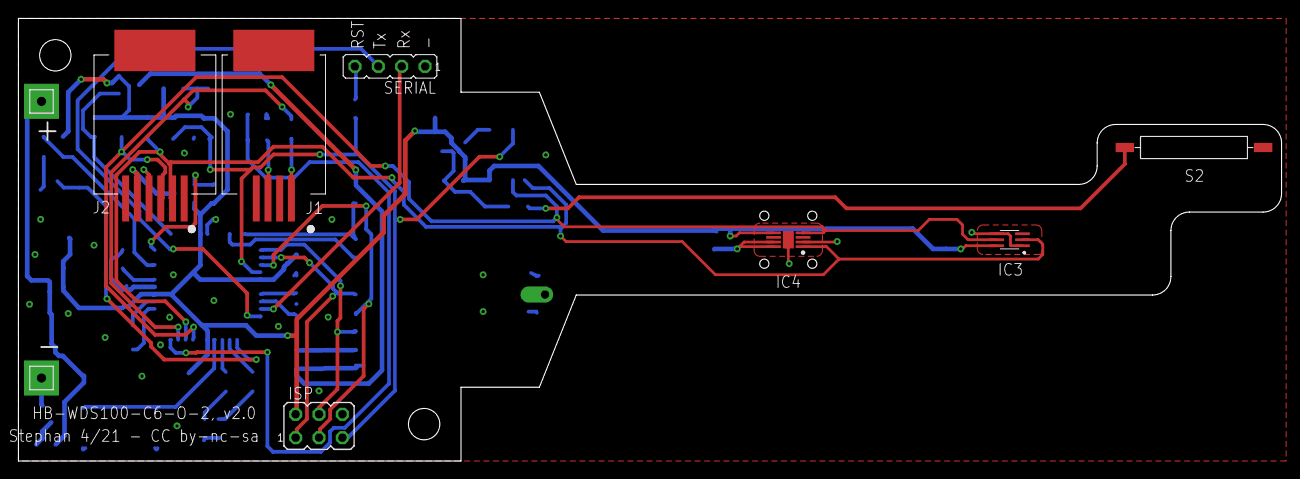
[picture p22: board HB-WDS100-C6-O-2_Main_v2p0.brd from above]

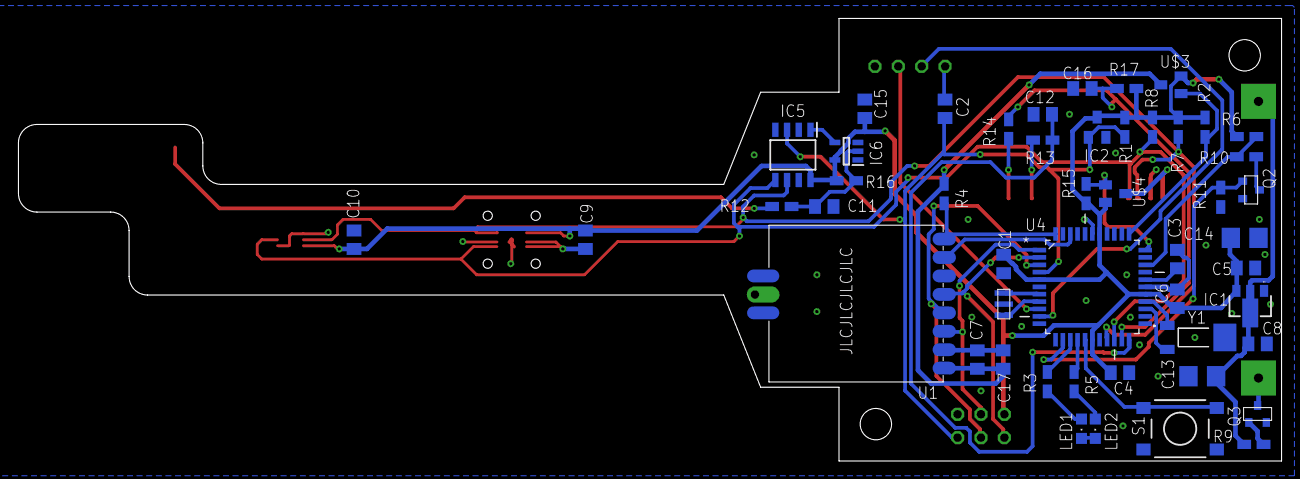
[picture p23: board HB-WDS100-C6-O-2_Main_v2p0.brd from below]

Board: 2 copper layers, 137.0 x 48.0 mm, 58 parts (49 on the bottom side), 40 nets.

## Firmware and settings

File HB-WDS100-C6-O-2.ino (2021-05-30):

//- -----------------------------------------------------------------------------------------------------------------------
// AskSin++
// 2016-10-31 papa Creative Commons - http://creativecommons.org/licenses/by-nc-sa/3.0/de/
// 2019-02-28 jp112sdl (Creative Commons)
//- -----------------------------------------------------------------------------------------------------------------------
// 2021-01-26 HB drop-in replacement for HM-WDS100-C6-O-2, HMSteve (Creative Commons by-nc-sa)
//- -----------------------------------------------------------------------------------------------------------------------

#define NDEBUG   // disable all serial debug messages 

#define EI_NOTEXTERNAL

#include <EnableInterrupt.h>
#include <AskSinPP.h>
#include <LowPower.h>
#include <Register.h>
#include <MultiChannelDevice.h>
#include "Wds100ConfigButton.h"
#include "PCF8593.h"
#include "sensors/Sens_SHT31.h"
#include "sensors/Sens_VEML6030.h"
#include "sensors/Sens_AS5600.h"
#include "sensors/tmBattery.h"  

#define CC1101_CS_PIN        4
#define CC1101_GDO0_PIN      2
#define CC1101_SCK_PIN       7 
#define CC1101_MOSI_PIN      5 
#define CC1101_MISO_PIN      6 
#define LED_PIN             13              
#define LED_PIN2            14
#define CONFIG_BUTTON_PIN   15
#define CC1101_PWR_SW_PIN   27
#define AS5600PWRSW_PIN     28 
#define RAINDETECTOR_PIN    18 
#define RAINCOUNTER_PIN     19  

#define BAT_VOLT_LOW                32    //3.2V for 3x Alkaline with 3V3 LDO
#define BAT_VOLT_CRITICAL           30  
#define PEERS_PER_CHANNEL            6
#define UPDATE_INTERVAL            183    //seconds. message transmission interval
#define HIGHFREQ_MEASURE_INTERVAL    5    //seconds. measurement interval wind speed and brightness
#define ANEMOMETER_CALIB_FACTOR     28    //empirical calib value ag. Windboss anemometer
#define NORTH_ANGLE_DEFAULT        140    //individual value if mounting direction is known, no need to change though

//#define CLOCK_SYSCLOCK
#define CLOCK_RTC


#ifdef CLOCK_SYSCLOCK
#define CLOCK sysclock
#define SAVEPWR_MODE Sleep<>
#elif defined CLOCK_RTC
#define CLOCK rtc
#define SAVEPWR_MODE SleepRTC
#undef seconds2ticks
#define seconds2ticks(tcks) (tcks)
#else
#error INVALID CLOCK OPTION
#endif



// tmBatteryLoad: sense pin, activation pin, Faktor = Rges/Rlow*1000, z.B. 10/30 Ohm, Faktor 40/10*1000 = 4000, 200ms Belastung vor Messung
// 1248p has 2.56V ARef, 328p has 1.1V ARef
#define BATT_SENSOR tmBatteryLoad<A6, 12, (uint16_t)(4000.0*2.56/1.1), 200>  



// all library classes are placed in the namespace 'as'
using namespace as;

volatile uint8_t _raindetector_isr_indicator = 0;
volatile uint32_t _raincounter_isr_counter = 0;



void raindetectorISR() {
  _raindetector_isr_indicator++;
  //save power by avoiding multiple interrupts during one measuring cycle, reenable in clock trigger function
  if (digitalPinToInterrupt(RAINDETECTOR_PIN) == NOT_AN_INTERRUPT) disableInterrupt(RAINDETECTOR_PIN); else detachInterrupt(digitalPinToInterrupt(RAINDETECTOR_PIN));  
}


void raincounterISR() {
  _raincounter_isr_counter++;
}




// define all device properties
const struct DeviceInfo PROGMEM devinfo = {
  {0xF8, 0x23, 0x01},     // Device ID
  "SGSENWDS01",           // Device Serial
  {0x00, 0xAE},           // Device Model HM-WDS100-C6-O-2
  0x10,                   // Firmware Version
  as::DeviceType::THSensor, // Device Type
  {0x01, 0x00}            // Info Bytes
};


// Configure the used hardware
typedef AvrSPI<CC1101_CS_PIN, CC1101_MOSI_PIN, CC1101_MISO_PIN, CC1101_SCK_PIN> SPIType;
typedef Radio<SPIType, CC1101_GDO0_PIN> RadioType;
typedef DualStatusLed<LED_PIN, LED_PIN2> LedType;
typedef AskSin<LedType, BATT_SENSOR, RadioType> BaseHal;

class Hal : public BaseHal {
  public:
    void init (const HMID& id) {
      BaseHal::init(id);
#ifdef CLOCK_RTC
      rtc.init();    // init real time clock - 1 tick per second
#endif
      // measure battery every a*b*c seconds
      battery.init(seconds2ticks(60UL * 60 * 12), CLOCK);  // 60UL * 60 for 1hour
      battery.low(BAT_VOLT_LOW);
      battery.critical(BAT_VOLT_CRITICAL);
    }

    bool runready () {
      return CLOCK.runready() || BaseHal::runready();
    }
} hal;

  
DEFREGISTER(Reg0, MASTERID_REGS, DREG_LEDMODE, DREG_TRANSMITTRYMAX, 0x01, 0x11, 0x18)
class Wds100List0 : public RegList0<Reg0> {
  public:
    Wds100List0(uint16_t addr) : RegList0<Reg0>(addr) {}

    bool liveModeRx (bool value) const {
      return this->writeRegister(0x01, value & 0xff);
    }
    bool liveModeRx () const {
      return this->readRegister(0x01, 0);
    }    

    bool cycleInfoMsgDis (uint8_t value) const {
      return this->writeRegister(0x11, value & 0xff);
    }
    uint8_t cycleInfoMsgDis () const {
      return this->readRegister(0x11, 0);
    }     

    bool localResetDisable (bool value) const {
      return this->writeRegister(0x18, value & 0xff);
    }
    bool localResetDisable () const {
      return this->readRegister(0x18, 0);
    }    
    
    void defaults () {
      clear();
      ledMode(0);
      transmitDevTryMax(6);     
      liveModeRx(false);
      localResetDisable(false);
      cycleInfoMsgDis(0);   
    }
};


DEFREGISTER(Reg1, 0x05, 0x06, 0x07, 0x0A, 0x20, 0x21)
class Wds100List1 : public RegList1<Reg1> {
  public:
    Wds100List1 (uint16_t addr) : RegList1<Reg1>(addr) {}

    bool sunshineThreshold (uint8_t value) const {
      return this->writeRegister(0x05, value & 0xff);
    }
    
    uint8_t sunshineThreshold () const {
      return this->readRegister(0x05, 0);
    } 
    
    bool stormUpperThreshold (uint8_t value) const {
      return this->writeRegister(0x06, value & 0xff);
    }
    
    uint8_t stormUpperThreshold () const {
      return this->readRegister(0x06, 0);
    }    
    
    bool stormLowerThreshold (uint8_t value) const {
      return this->writeRegister(0x07, value & 0xff);
    }
    
    uint8_t stormLowerThreshold () const {
      return this->readRegister(0x07, 0);
    }   
    
    bool windSpeedResultSource (uint8_t value) const {
      return this->writeRegister(0x0A, value & 0xff);
    }
    
    uint8_t windSpeedResultSource () const {
      return this->readRegister(0x0A, 0);
    }     

    bool northAngle (uint16_t value) const {
      return this->writeRegister(0x20, (value >> 8) & 0xff) && this->writeRegister(0x21, value & 0xff);
    }
    
    uint16_t northAngle () const {
      return (this->readRegister(0x20, 0) << 8) + this->readRegister(0x21, 0);
    }

    void defaults () {
      clear();
      sunshineThreshold(0);
      stormUpperThreshold(0);
      stormLowerThreshold(0);
      windSpeedResultSource(0);
      northAngle(NORTH_ANGLE_DEFAULT);
    }
};     


class Wds100EventMsg : public Message {
  public:
    void init(uint8_t msgcnt, int16_t temperature, uint8_t humidity, uint8_t raining, uint16_t rain_counter, uint16_t wind_speed, uint8_t wind_direction, uint8_t wind_direction_range, uint8_t sunshineduration, uint8_t brightness, bool batlow) {
      uint8_t t1 = (temperature >> 8) & 0x7f;
      uint8_t t2 = temperature & 0xff;
      if ( batlow == true ) {
        t1 |= 0x80; // set bat low bit
      }
      uint8_t flags = 0;
      // Message Length (first byte param.): 11 + payload. Max. payload: 17 Bytes (https://www.youtube.com/watch?v=uAyzimU60jw)
      Message::init(19, msgcnt, 0x70, flags, t1, t2);
      pload[0] = humidity & 0xff;
      pload[1] = ((rain_counter >> 8) & 0x7f) | (raining << 7);
      pload[2] = (rain_counter) & 0xff;      
      pload[3] = ((wind_speed >> 8) & 0x3f) | (wind_direction_range << 6);
      pload[4] = (wind_speed) & 0xff;        
      pload[5] = wind_direction & 0xff;         
      pload[6] = sunshineduration & 0xff;
      pload[7] = brightness & 0xff;
    }
};


class Wds100Channel : public Channel<Hal, Wds100List1, EmptyList, List4, PEERS_PER_CHANNEL, Wds100List0>, public Alarm {
    Sens_SHT31<0x44>    sht31;
    Sens_VEML6030<0x10> veml6030;
    Sens_AS5600         as5600; 
    PCF8593             pcf8593;  
    int16_t  temperature = 0;
    uint8_t  humidity = 0;
    uint8_t  raining = 0;    
    uint16_t rain_counter = 0; 
    uint16_t wind_speed = 0; 
    uint8_t  wind_direction = 0;  
    uint8_t  wind_direction_range = 0;  
    uint8_t  sunshineduration = 0;  
    uint8_t  brightness = 0;   
    uint16_t ws_total = 0; 
    uint16_t ws_measure_count = 0;  
    uint16_t wind_speed_avg = 0; 
    uint16_t wind_speed_gust = 0;      
    uint16_t  stormUpperThreshold;
    uint16_t  stormLowerThreshold;        
                           
  public:
    Wds100Channel () : Channel(), Alarm(10), hfMeasureAlarm(*this) {}
    
    virtual ~Wds100Channel () {}

    class HighFreqMeasureAlarm : public Alarm {
        Wds100Channel& chan;
        uint16_t ssh_total;
        
      public:
        HighFreqMeasureAlarm (Wds100Channel& c) : Alarm (seconds2ticks(HIGHFREQ_MEASURE_INTERVAL)), chan(c), ssh_total(0) {}
        
        virtual ~HighFreqMeasureAlarm () {}

        void trigger (__attribute__ ((unused)) AlarmClock& clock)  {
          chan.measure_windspeed();

          chan.veml6030.measure();
          chan.brightness = chan.veml6030.brightness();  
          if (chan.brightness >= chan.getList1().sunshineThreshold()) {
            if (ssh_total < 255 * 60 - HIGHFREQ_MEASURE_INTERVAL) {
              ssh_total += HIGHFREQ_MEASURE_INTERVAL;
            }
            else {
              ssh_total = (HIGHFREQ_MEASURE_INTERVAL - (255 * 60 - ssh_total));
            }
          }
          // guess it's night when dark, so reset sunshine duration counter
          if (chan.veml6030.brightness() < 1) {
            ssh_total = 0;
          }
          chan.sunshineduration = ssh_total / 60;
          DPRINT("mLux / 8-bit brightness = ");DDEC(chan.veml6030.milliLux()); DPRINT(" / "); DDECLN(chan.veml6030.brightness());

          chan.pcf8593.resetCounter();
          tick = (seconds2ticks(HIGHFREQ_MEASURE_INTERVAL));
          clock.add(*this);
        }
    } hfMeasureAlarm;


    virtual void trigger (AlarmClock& clock) {
      sht31.measure();
      temperature = sht31.temperature();
      humidity = sht31.humidity();        
      measure_winddir();
      evaluate_windspeed();   
      measure_raining();   
      rain_counter = _raincounter_isr_counter;
      DPRINT("wind dir angle / corrected wind dir  = ");DDEC(as5600.angle()); DPRINT(" / "); DDECLN(wind_direction * 5);
      DPRINT("windspeed avg / gust / reported km/h = ");DDEC(wind_speed_avg); DPRINT(" / ");DDEC(wind_speed_gust); DPRINT(" / ");DDECLN(wind_speed);
      DPRINT("raining =                              ");DDECLN(raining);
      Wds100EventMsg& msg = (Wds100EventMsg&)device().message();
      uint8_t msgcnt = device().nextcount();      
      msg.init( msgcnt, temperature, humidity, raining, rain_counter, wind_speed, wind_direction, wind_direction_range, sunshineduration, brightness, device().battery().low());
      // BIDI|WKMEUP every 20th msg      
      if ((msgcnt % 20) == 1) {
          DPRINTLN("sendMasterEvent");
          msg.flags(Message::BIDI | Message::WKMEUP);
          device().sendMasterEvent(msg);
      } else {
          DPRINTLN("broadcastEvent");
          msg.flags(Message::BCAST);  
          device().broadcastEvent(msg);
      }
      
      wind_speed_gust = 0;
      set(seconds2ticks(UPDATE_INTERVAL * (this->device().getList0().cycleInfoMsgDis() + 1)));
      clock.add(*this);
    }

    void measure_windspeed() {
      uint16_t ws = pcf8593.getCount();
      ws_total += ws;
      ws = uint16_t(ANEMOMETER_CALIB_FACTOR * ws / HIGHFREQ_MEASURE_INTERVAL);     
      if (ws > wind_speed_gust) {
        wind_speed_gust = ws;
      } 
      ws_measure_count++;   
      DPRINT("current windspeed km/h * 10 = ");DDECLN(ws);

      static uint8_t STORM_COND_VALUE_Last = 0;
      static uint8_t STORM_COND_VALUE      = 0;

      if (stormUpperThreshold > 0) {
        if (ws >= stormUpperThreshold || ws <= stormLowerThreshold) {
          static uint8_t evcnt = 0;
          if (ws >= stormUpperThreshold) STORM_COND_VALUE = 1;
          if (ws <= stormLowerThreshold) STORM_COND_VALUE = 0;          

          if (STORM_COND_VALUE != STORM_COND_VALUE_Last) {
            SensorEventMsg& rmsg = (SensorEventMsg&)device().message();
            DPRINT(F("PEER THRESHOLD DETECTED : ")); DDECLN(STORM_COND_VALUE);
            rmsg.init(device().nextcount(), number(), evcnt++, ws / 10, false , false);           
            rmsg.flags(Message::BIDI | Message::WKMEUP);
            device().sendPeerEvent(rmsg, *this);
          }
          STORM_COND_VALUE_Last = STORM_COND_VALUE;
        }
      }
    }


    void evaluate_windspeed() {
      wind_speed_avg = uint16_t(ANEMOMETER_CALIB_FACTOR * ws_total / HIGHFREQ_MEASURE_INTERVAL / ws_measure_count);
      if (this->getList1().windSpeedResultSource() == 1) {
        wind_speed = wind_speed_gust;
      }
      else {
        wind_speed = wind_speed_avg;        
      }
      ws_total = 0;
      ws_measure_count = 0;      
    }


    void measure_winddir() {
      int16_t wdr = 0;
      uint16_t wdold = as5600.angle();
      pinMode(AS5600PWRSW_PIN, OUTPUT);   
      digitalWrite(AS5600PWRSW_PIN, LOW);
      delay(10); //power-up time       
      as5600.init(); 
      as5600.measure(); 
      pinMode(AS5600PWRSW_PIN, INPUT); 
      if (as5600.angle() > this->getList1().northAngle()) {
        wind_direction = (as5600.angle() - this->getList1().northAngle()) / 5;    
      } else {
        wind_direction = (as5600.angle() +360 - this->getList1().northAngle()) / 5;
      }
      wdr = as5600.angle() - wdold;
      wdr = abs(wdr);
      if (wdr > 180) {
        wdr = 360 - wdr;                    
      }
      if (wdr < 22) {
        wind_direction_range = 0;
      } else if ((wdr >= 22) and (wdr <45)) {
        wind_direction_range = 1;  
      } else if ((wdr >= 45) and (wdr <67)) {
        wind_direction_range = 2;  
      } else {
        wind_direction_range = 3;           
      }
      DPRINT("Wind dir old / new / range / sent val : ");DDEC(wdold);DPRINT(" / ");DDEC(as5600.angle());DPRINT(" / ");DDEC(wdr);DPRINT(" / ");DDECLN(wind_direction_range);
    }


    uint16_t get_winddir_angle() {
      measure_winddir();
      return as5600.angle();
    }


    void measure_raining(){
      raining = _raindetector_isr_indicator;
      if(digitalRead(RAINDETECTOR_PIN) == 1) {
        _raindetector_isr_indicator = 0;
        if ( digitalPinToInterrupt(RAINDETECTOR_PIN) == NOT_AN_INTERRUPT ) enableInterrupt(RAINDETECTOR_PIN, raindetectorISR, FALLING); else attachInterrupt(digitalPinToInterrupt(RAINDETECTOR_PIN), raindetectorISR, FALLING);  
      }      
    }

    
    void setup(Device<Hal, Wds100List0>* dev, uint8_t number, uint16_t addr) {
      Channel::setup(dev, number, addr);
      sht31.init();
      veml6030.init();
      pcf8593.init();
      set(seconds2ticks(2));  // first message in 2 sec.      
      CLOCK.add(*this);
      CLOCK.add(hfMeasureAlarm);      
    }

    uint8_t status () const {
      return 0;
    }

    uint8_t flags () const {
      return 0;
    }

    void configChanged() {
      Channel::configChanged();
      stormUpperThreshold = this->getList1().stormUpperThreshold() * 10;
      stormLowerThreshold = this->getList1().stormLowerThreshold() * 10;      
      DPRINTLN("* Channel Conf Changed : Wds100List1");
      DPRINT(F("* Sonnescheinschwelle  : ")); DDECLN(this->getList1().sunshineThreshold()); 
      DPRINT(F("* Sturm obere Schwelle : ")); DDECLN(this->getList1().stormUpperThreshold());  
      DPRINT(F("* Sturm untere Schwelle: ")); DDECLN(this->getList1().stormLowerThreshold());       
      DPRINT(F("* Art Windgeschw.      : ")); DDECLN(this->getList1().windSpeedResultSource());
      DPRINT(F("* Winkel Nord          : ")); DDECLN(this->getList1().northAngle());      
    }
};


class Wds100Device : public MultiChannelDevice<Hal, Wds100Channel, 1, Wds100List0> {
  public:
    typedef MultiChannelDevice<Hal, Wds100Channel, 1, Wds100List0> TSDevice;
    
    Wds100Device(const DeviceInfo& info, uint16_t addr) : TSDevice(info, addr) {}
    
    virtual ~Wds100Device () {}

    virtual void configChanged () {
      TSDevice::configChanged();
      DPRINTLN("* Device Conf Changed  : Wds100List0");
      DPRINT(F("* LED Mode             : ")); DDECLN(this->getList0().ledMode());    
      DPRINT(F("* Sendeversuche        : ")); DDECLN(this->getList0().transmitDevTryMax());          
      DPRINT(F("* Live Mode            : ")); DDECLN(this->getList0().liveModeRx());     
      DPRINT(F("* Auszul. Meldungen    : ")); DDECLN(this->getList0().cycleInfoMsgDis());          
      DPRINT(F("* Local Reset Disable  : ")); DDECLN(this->getList0().localResetDisable());  
    }

    void setNorth () {
      uint16_t north = Wds100Channel().get_winddir_angle();
      this->channel(0).getList1().northAngle(north);     
      DPRINT("North angle stored in List 1 : "); DDECLN(this->channel(0).getList1().northAngle());       
    }
};



Wds100Device sdev(devinfo, 0x20);
Wds100ConfigButton<Wds100Device> cfgBtn(sdev);


void setup () {
  //switch on MOSFET to power CC1101
  pinMode(CC1101_PWR_SW_PIN, OUTPUT); 
  digitalWrite (CC1101_PWR_SW_PIN, LOW);
  DINIT(57600, ASKSIN_PLUS_PLUS_IDENTIFIER);
  sdev.init(hal);
   
  buttonISR(cfgBtn, CONFIG_BUTTON_PIN);
  sdev.initDone();
  //sdev.getList0().dump();
  //sdev.channel(0).getList1().dump();
  
  pinMode(RAINDETECTOR_PIN, INPUT); //large ext pullup to save power during rain
  pinMode(RAINCOUNTER_PIN, INPUT);  
  if ( digitalPinToInterrupt(RAINCOUNTER_PIN) == NOT_AN_INTERRUPT ) enableInterrupt(RAINCOUNTER_PIN, raincounterISR, CHANGE); else attachInterrupt(digitalPinToInterrupt(RAINCOUNTER_PIN), raincounterISR, CHANGE);  
}


void loop() {
  bool worked = hal.runready();
  bool poll = sdev.pollRadio();
  if ( worked == false && poll == false ) {
    hal.activity.savePower<SAVEPWR_MODE>(hal);
  }
}

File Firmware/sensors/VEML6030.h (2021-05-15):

/*
  HMSteve 14/05/2021: VEML6030 lib code copied from Sprakfun lib, output in mLux to better utilise dynamic range of sensor

  credits :
  This is a library for SparkFun's VEML6030 Ambient Light Sensor (Qwiic)
  By: Elias Santistevan
  Date: July 2019
  License: This code is public domain but you buy me a beer if you use this and
  we meet someday (Beerware license).
  Feel like supporting our work? Buy a board from SparkFun!
 */


 #define ENABLE        0x01
 #define DISABLE       0x00
 #define SHUTDOWN      0x01
 #define POWER         0x00
 #define NO_INT        0x00
 #define INT_HIGH      0x01
 #define INT_LOW       0x02
 #define UNKNOWN_ERROR 0xFF

 // 7-Bit address options
 const uint8_t defAddr = 0x48;
 const uint8_t altAddr = 0x10;

 enum VEML6030_16BIT_REGISTERS {

   SETTING_REG            = 0x00,
   H_THRESH_REG,
   L_THRESH_REG,
   POWER_SAVE_REG,
   AMBIENT_LIGHT_DATA_REG,
   WHITE_LIGHT_DATA_REG,
   INTERRUPT_REG

 };

 enum VEML6030_16BIT_REG_MASKS {

   THRESH_MASK            = 0x0,
   GAIN_MASK              = 0xE7FF,
   INTEG_MASK             = 0xFC3F,
   PERS_PROT_MASK         = 0xFFCF,
   INT_EN_MASK            = 0xFFFD,
   SD_MASK                = 0xFFFE,
   POW_SAVE_EN_MASK       = 0x06, // Most of this register is reserved
   POW_SAVE_MASK          = 0x01, // Most of this register is reserved
   INT_MASK               = 0xC000

 };

 enum REGISTER_BIT_POSITIONS {

   NO_SHIFT               = 0x00,
   INT_EN_POS             = 0x01,
   PSM_POS                = 0x01,
   PERS_PROT_POS          = 0x04,
   INTEG_POS              = 0x06,
   GAIN_POS               = 0xB,
   INT_POS                = 0xE

 };

 // Table of lux conversion values depending on the integration time and gain.
 // The arrays represent the all possible integration times and the index of the
 // arrays represent the register's gain settings, which is directly analgous to
 // their bit representations.
 const float eightHIt[]     = {.0036, .0072, .0288, .0576};
 const float fourHIt[]      = {.0072, .0144, .0576, .1152};
 const float twoHIt[]       = {.0144, .0288, .1152, .2304};
 const float oneHIt[]       = {.0288, .0576, .2304, .4608};
 const float fiftyIt[]      = {.0576, .1152, .4608, .9216};
 const float twentyFiveIt[] = {.1152, .2304, .9216, 1.8432};


class VEML6030
{
private:
  uint8_t _address;
  TwoWire *_i2cPort;

  // This function compensates for lux values over 1000. From datasheet:
  // "Illumination values higher than 1000 lx show non-linearity. This
  // non-linearity is the same for all sensors, so a compensation forumla..."
  // etc. etc.
  uint32_t _luxCompensation(uint32_t _luxVal){

    // Polynomial is pulled from pg 10 of the datasheet.
    uint32_t _compLux = (.00000000000060135 * (pow(_luxVal, 4))) -
                        (.0000000093924 * (pow(_luxVal, 3))) +
                        (.000081488 * (pow(_luxVal,2))) +
                        (1.0023 * _luxVal);
    return _compLux;

  }

  // The lux value of the Ambient Light sensor depends on both the gain and the
  // integration time settings. This function determines which conversion value
  // to use by using the bit representation of the gain as an index to look up
  // the conversion value in the correct integration time array. It then converts
  // the value and returns it.
  uint32_t _calculateLux(uint16_t _lightBits){

    float _luxConv;
    uint8_t _convPos;

    float _gain = readGain();
    uint16_t _integTime = readIntegTime();

    // Here the gain is checked to get the position of the conversion value
    // within the integration time arrays. These values also represent the bit
    // values for setting the gain.
    if (_gain == 2.00)
      _convPos = 0;
    else if (_gain == 1.00)
      _convPos = 1;
    else if (_gain == .25)
      _convPos = 2;
    else if (_gain == .125)
      _convPos = 3;
    else
      return UNKNOWN_ERROR;

    // Here we check the integration time which determines which array we probe
    // at the position determined above.
    if(_integTime == 800)
      _luxConv = eightHIt[_convPos];
    else if(_integTime == 400)
      _luxConv = fourHIt[_convPos];
    else if(_integTime == 200)
      _luxConv = twoHIt[_convPos];
    else if(_integTime == 100)
      _luxConv = oneHIt[_convPos];
    else if(_integTime == 50)
      _luxConv = fiftyIt[_convPos];
    else if(_integTime == 25)
      _luxConv = twentyFiveIt[_convPos];
    else
      return UNKNOWN_ERROR;

    // Multiply the value from the 16 bit register to the conversion value and return
    // it.
    // Multiply by 1000 to better utilise dynamic range, output mLux
    uint32_t _calculatedLux = (_luxConv * _lightBits);
    return _calculatedLux;

  }

  // The lux value of the Ambient Light sensor depends on both the gain and the
  // integration time settings. This function determines which conversion value
  // to use by using the bit representation of the gain as an index to look up
  // the conversion value in the correct integration time array. It then converts
  // the value and returns it.
  uint32_t _calculateMilliLux(uint16_t _lightBits){

    float _luxConv;
    uint8_t _convPos;

    float _gain = readGain();
    uint16_t _integTime = readIntegTime();

    // Here the gain is checked to get the position of the conversion value
    // within the integration time arrays. These values also represent the bit
    // values for setting the gain.
    if (_gain == 2.00)
      _convPos = 0;
    else if (_gain == 1.00)
      _convPos = 1;
    else if (_gain == .25)
      _convPos = 2;
    else if (_gain == .125)
      _convPos = 3;
    else
      return UNKNOWN_ERROR;

    // Here we check the integration time which determines which array we probe
    // at the position determined above.
    if(_integTime == 800)
      _luxConv = eightHIt[_convPos];
    else if(_integTime == 400)
      _luxConv = fourHIt[_convPos];
    else if(_integTime == 200)
      _luxConv = twoHIt[_convPos];
    else if(_integTime == 100)
      _luxConv = oneHIt[_convPos];
    else if(_integTime == 50)
      _luxConv = fiftyIt[_convPos];
    else if(_integTime == 25)
      _luxConv = twentyFiveIt[_convPos];
    else
      return UNKNOWN_ERROR;

    // Multiply the value from the 16 bit register to the conversion value and return
    // it.
    // Multiply by 1000 to better utilise dynamic range, output mLux
    uint32_t _calculatedLux = (1000.0 * _luxConv * _lightBits);
    return _calculatedLux;

  }


  // This function does the opposite calculation then the function above. The interrupt
  // threshold values given by the user are dependent on the gain and
  // intergration time settings. As a result the lux value needs to be
  // calculated with the current settings and this function accomplishes
  // that.
  uint16_t _calculateBits(uint32_t _luxVal){

    float _luxConv;
    uint8_t _convPos;
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

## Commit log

2021-05-22 anemometer calib added
    [WindspeedCalib.xlsx]
2021-05-23 pcb added
    [BOM_Draft.xlsx, WindspeedCalib.xlsx]
2021-05-23 schematic v2.1 added
2021-06-10 BOM added
    [BOM_Draft.xlsx, SourcingSpecialParts.xlsx]
2024-01-03 Eagle files added
    [HB-WDS100-C6-O-2_Main_v2p0.brd, HB-WDS100-C6-O-2_Main_v2p0.sch, HB-WDS100-C6-O-2_WindDir_v1p0.brd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]

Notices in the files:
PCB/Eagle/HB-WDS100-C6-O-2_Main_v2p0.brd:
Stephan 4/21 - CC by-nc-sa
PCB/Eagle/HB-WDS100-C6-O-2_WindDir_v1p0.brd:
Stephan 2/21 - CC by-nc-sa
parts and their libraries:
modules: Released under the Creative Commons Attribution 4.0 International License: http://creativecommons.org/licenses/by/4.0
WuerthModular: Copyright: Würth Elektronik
